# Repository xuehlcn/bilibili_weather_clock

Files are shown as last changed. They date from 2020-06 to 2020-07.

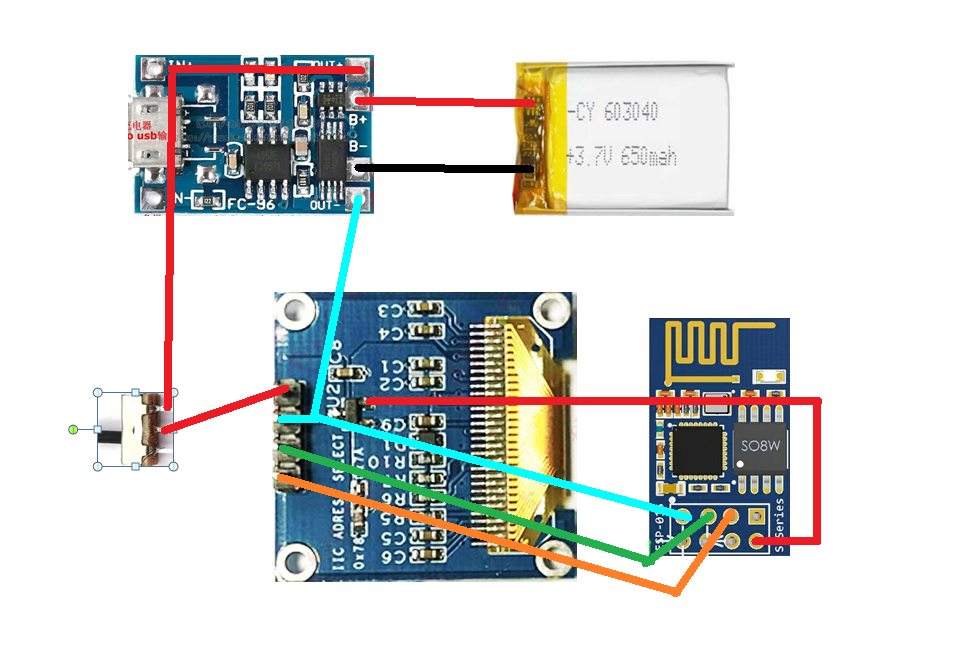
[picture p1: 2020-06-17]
接线/电路接线.png

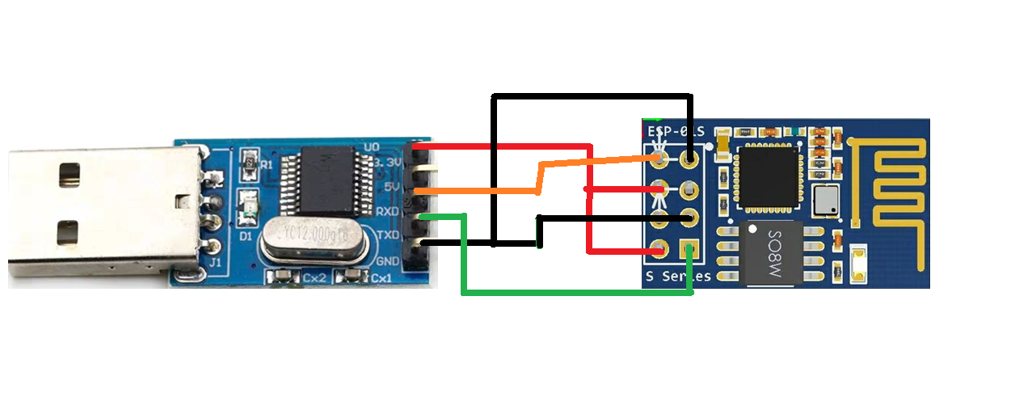
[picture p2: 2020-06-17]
接线/上传程序接线.png

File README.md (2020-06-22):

# 哔哩哔哩网络天气时钟小电视（太极创客小凯制作）

### 观看该项目可点击视频地址：https://www.bilibili.com/video/BV1FV411k7Pq/

输入图片说明

输入图片说明

## 材料
| 材料 | 规格 | 参考价格 |
| --- | ---| --- |
| ESP01s | 或者其他型号，尺寸合适即可 | 6-7元 |
| OLED | 0.96寸，带3.3V稳压，尺寸见下方图片 | 9-11元 |
| 3.7V充电模块 | 见下方图片 | 1-2元 |
| 3.7V锂电池 | 型号602525或者502525，尺寸见下方图片  | 5-7元 |
| 三脚开关 | 宽3.7长8.5 | 0.1元 |
| 外壳 | 见3D文件 | |
| 线 | 若干 | |
| 亚克力 | 见图纸CAD | 5元 |
| 螺钉 | M2*10 | 1元 |
| USB转TTL | 有3.3V的 | 3-5元 |

输入图片说明

## 焊接/连线  
上传程序接线

| ESP01S | USB-TTF |
| --- | --- |
| GND | GND |
| 3.3V | 3.3V |
| RX | TX |
| TX | RX |
| EN | 3.3V |
| IO0 | GND |

输入图片说明

主电路接线

（注意ESP01模块的VCC是接在OLED屏幕的3.3V降压管的引脚上哦，还有就是你的模块引脚跟图片可能不一样，注意区分，灵活变通）

| ESP01S | OLED |
| --- | --- |
| 3.3V | 3.3V降压管 |
| GND | GND |
| IO0 | SDA |
| IO2 | SCL |

输入图片说明

## 3D打印外壳 
见3D文件夹，可自行修改

目前只针对0.96寸

1.3寸后期更新

## 程序  
需要修改的地方修改的地方我已在程序注释，请小伙伴认真阅读 

## 其他
网络时钟目前获取的是中科院以及阿里云的NTP

天气用的是和风天气API，可百度搜索并自行注册

## 太极创客团队信息

太极创客官网地址：http://www.taichi-maker.com/

太极创客哔哩哔哩主页：https://space.bilibili.com/103589285

太极创客YouTube：https://www.youtube.com/channel/UC8EkxMr5gGnrb9adVgR-UJw

太极创客GitHub：https://github.com/taichi-maker

太极创客码云：https://gitee.com/taijichuangke

## ESP8266-Seniverse库项目开发人员

小凯：https://gitee.com/xiaoxiaokai

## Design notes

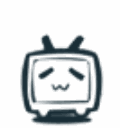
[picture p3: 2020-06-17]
取模软件/小电视动画1/xiaodianshi(2).gif

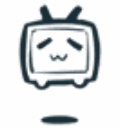
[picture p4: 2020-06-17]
取模软件/小电视动画1/xiaodianshi(2)_4.jpeg

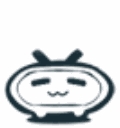
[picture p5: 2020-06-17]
取模软件/小电视动画1/xiaodianshi(2)_6.jpeg

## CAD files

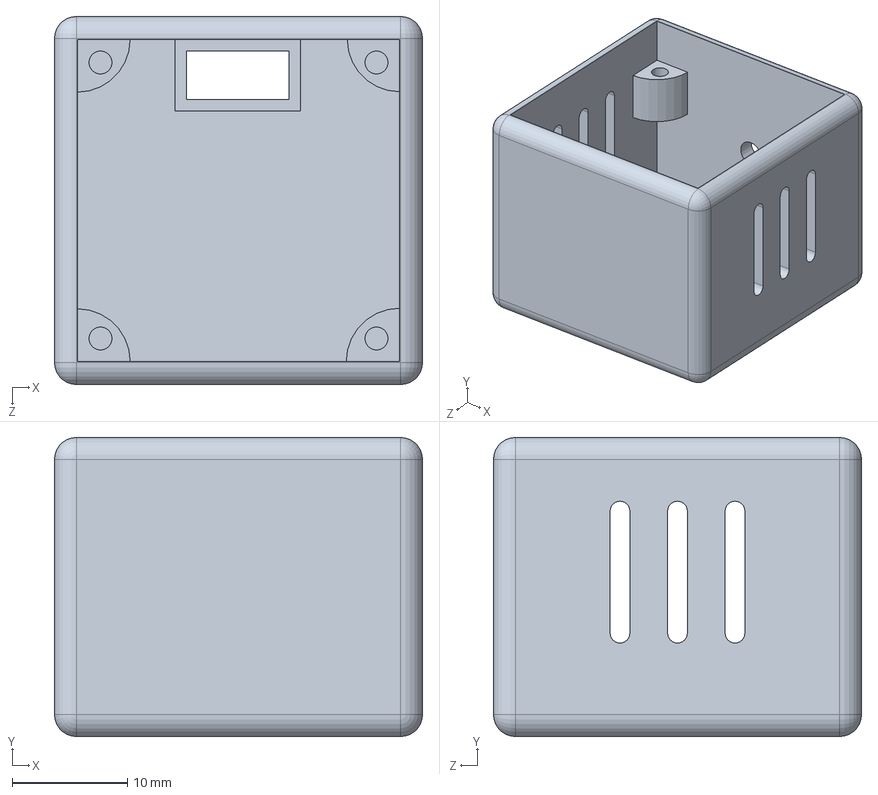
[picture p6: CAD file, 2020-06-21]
小电视3D文件/小电视 - 带散热孔.SLDPRT
32.0 x 26.0 x 32.0 mm

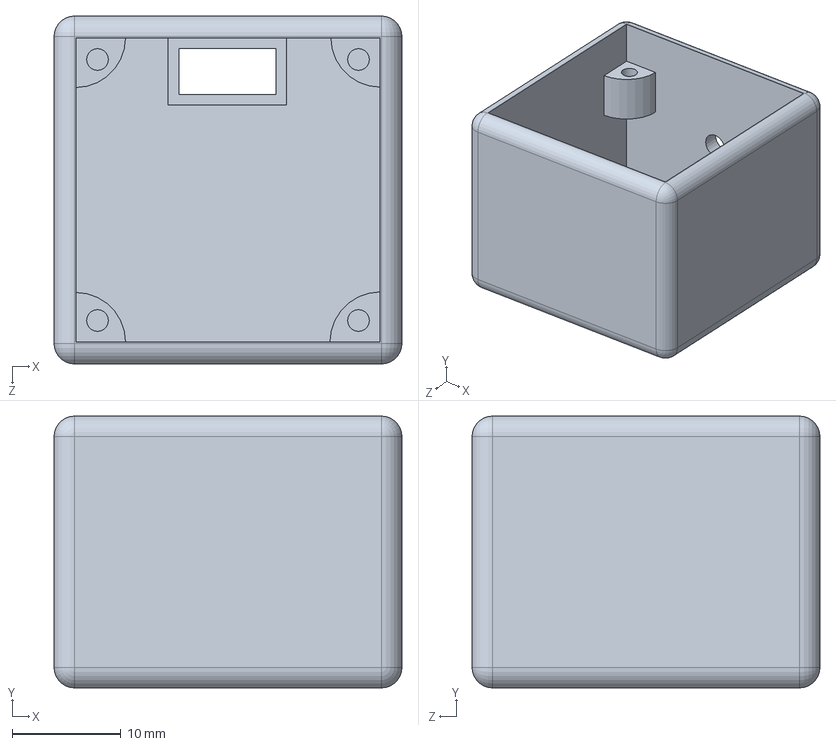
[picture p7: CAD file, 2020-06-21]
小电视3D文件/小电视.SLDPRT
32.0 x 25.0 x 32.0 mm

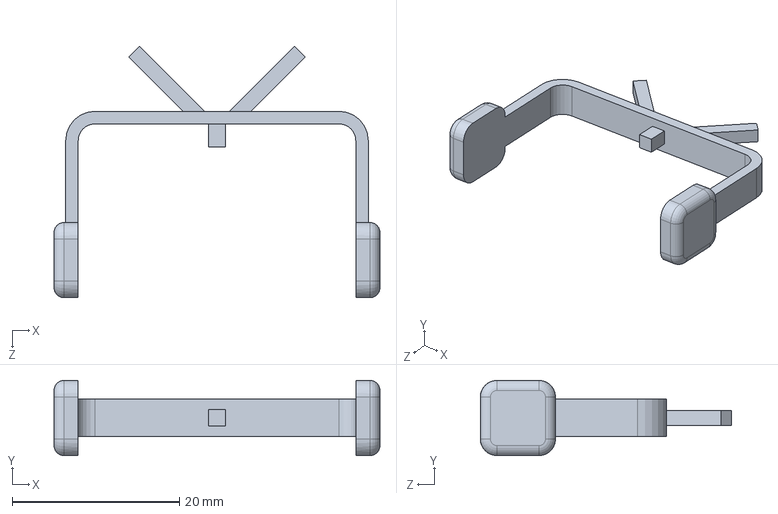
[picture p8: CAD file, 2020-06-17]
小电视3D文件/耳机天线.SLDPRT
39.0 x 9.00 x 30.1 mm

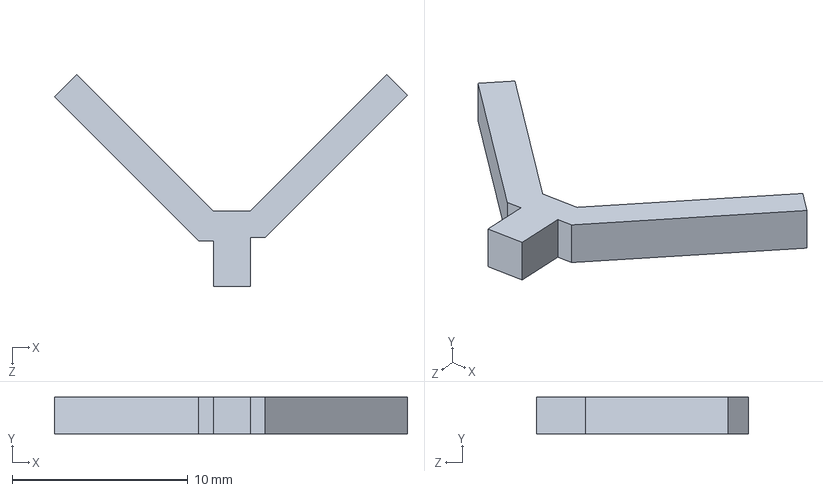
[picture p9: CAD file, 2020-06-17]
小电视3D文件/天线.SLDPRT
20.1 x 2.10 x 12.1 mm

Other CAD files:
小电视3D文件/CAD亚克力/2毫米厚.dwg
小电视3D文件/天线.STL
小电视3D文件/小电视 - 带散热孔.STL
小电视3D文件/小电视.STL
小电视3D文件/耳机天线.STL

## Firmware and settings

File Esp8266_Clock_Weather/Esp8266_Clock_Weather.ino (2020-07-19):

#include <Arduino.h>
#include <ESP8266WiFi.h>
#include <ESP8266HTTPClient.h>

#include <DNSServer.h>//密码直连将其三个库注释
#include <ESP8266WebServer.h>
#include <CustomWiFiManager.h>

#include <time.h>                       
#include <sys/time.h>                  
#include <coredecls.h>      


//#include "SH1106Wire.h"   //1.3寸用这个
#include "SSD1306Wire.h"    //0.96寸用这个
#include "OLEDDisplayUi.h"
#include "HeFeng.h"
#include "WeatherStationFonts.h"
#include "WeatherStationImages.h"

/***************************
   Begin Settings
 **************************/

const char* WIFI_SSID = "xiaokai";  //填写你的WIFI名称及密码
const char* WIFI_PWD = "12345678k";

const char* BILIBILIID = "167480182";  //填写你的B站账号

//由于太多人使用我的秘钥，导致获取次数超额，所以不提供秘钥了，大家可以到https://dev.heweather.com/获取免费的
const char* HEFENG_KEY = "xxxxxxxxxxxxxxxxxxxxxx";//填写你的和风天气秘钥
const char* HEFENG_LOCATION = "CN101290703";//填写你的城市ID,可到https://where.heweather.com/index.html查询
//const char* HEFENG_LOCATION = "auto_ip";//自动IP定位

#define TZ              8      // 中国时区为8
#define DST_MN          0      // 默认为0

const int UPDATE_INTERVAL_SECS = 5 * 60; // 5分钟更新一次天气
const int UPDATE_CURR_INTERVAL_SECS = 2 * 59; // 2分钟更新一次粉丝数

const int I2C_DISPLAY_ADDRESS = 0x3c;  //I2c地址默认
#if defined(ESP8266)
const int SDA_PIN = 0;  //引脚连接
const int SDC_PIN = 2;  //
#endif

const String WDAY_NAMES[] = {"Sun", "Mon", "Tue", "Wed", "Thu", "Fri", "Sat"};  //星期
const String MONTH_NAMES[] = {"Jan", "Feb", "Mar", "Apr", "May", "Jun", "Jul", "Aug", "Sep", "Oct", "Nov", "Dec"};  //月份

// web配网页面自定义我的图标请随便使用一个图片转base64工具转换https://tool.css-js.com/base64.html, 64*64
const char Icon[] PROGMEM = "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";

/***************************
   End Settings
 **************************/
 
//SH1106Wire     display(I2C_DISPLAY_ADDRESS, SDA_PIN, SDC_PIN);   // 1.3寸用这个
SSD1306Wire     display(I2C_DISPLAY_ADDRESS, SDA_PIN, SDC_PIN);   // 0.96寸用这个
OLEDDisplayUi   ui( &display );

HeFengCurrentData currentWeather; //实例化对象
HeFengForeData foreWeather[3];
HeFeng HeFengClient;

#define TZ_MN           ((TZ)*60)   //时间换算
#define TZ_SEC          ((TZ)*3600)
#define DST_SEC         ((DST_MN)*60)

time_t now; //实例化时间

bool readyForWeatherUpdate = false; // 天气更新标志
bool first = true;  //首次更新标志
long timeSinceLastWUpdate = 0;    //上次更新后的时间
long timeSinceLastCurrUpdate = 0;   //上次天气更新后的时间

String fans = "-1"; //粉丝数

void drawProgress(OLEDDisplay *display, int percentage, String label);   //提前声明函数
void updateData(OLEDDisplay *display);
void updateDatas(OLEDDisplay *display);
void drawDateTime(OLEDDisplay *display, OLEDDisplayUiState* state, int16_t x, int16_t y);
void drawCurrentWeather(OLEDDisplay *display, OLEDDisplayUiState* state, int16_t x, int16_t y);
void drawForecast(OLEDDisplay *display, OLEDDisplayUiState* state, int16_t x, int16_t y);
void drawForecastDetails(OLEDDisplay *display, int x, int y, int dayIndex);
void drawHeaderOverlay(OLEDDisplay *display, OLEDDisplayUiState* state);
void setReadyForWeatherUpdate();

//添加框架
//此数组保留指向所有帧的函数指针
//框架是从右向左滑动的单个视图
FrameCallback frames[] = { drawDateTime, drawCurrentWeather, drawForecast };
//页面数量
int numberOfFrames = 3;

OverlayCallback overlays[] = { drawHeaderOverlay }; //覆盖回调函数
int numberOfOverlays = 1;  //覆盖数

void setup() {
  Serial.begin(115200);
  Serial.println();
  Serial.println();

  // 屏幕初始化
  display.init();
  display.clear();
  display.display();

  display.flipScreenVertically(); //屏幕翻转
  display.setContrast(255); //屏幕亮度

  //Web配网，密码直连请注释
  webconnect();
  
  // 用固定密码连接，Web配网请注释
  //wificonnect();

  ui.setTargetFPS(30);  //刷新频率

  ui.setActiveSymbol(activeSymbole); //设置活动符号
  ui.setInactiveSymbol(inactiveSymbole); //设置非活动符号

  // 符号位置
  // 你可以把这个改成TOP, LEFT, BOTTOM, RIGHT
  ui.setIndicatorPosition(BOTTOM);

  // 定义第一帧在栏中的位置
  ui.setIndicatorDirection(LEFT_RIGHT);

  // 屏幕切换方向
  // 您可以更改使用的屏幕切换方向 SLIDE_LEFT, SLIDE_RIGHT, SLIDE_TOP, SLIDE_DOWN
  ui.setFrameAnimation(SLIDE_LEFT);

  ui.setFrames(frames, numberOfFrames); // 设置框架
  ui.setTimePerFrame(5000); //设置切换时间
  
  ui.setOverlays(overlays, numberOfOverlays); //设置覆盖

  // UI负责初始化显示
  ui.init();
  display.flipScreenVertically(); //屏幕反转

  configTime(TZ_SEC, DST_SEC, "ntp.ntsc.ac.cn", "ntp1.aliyun.com"); //ntp获取时间，你也可用其他"pool.ntp.org","0.cn.pool.ntp.org","1.cn.pool.ntp.org","ntp1.aliyun.com"
  delay(200);

}

void loop() {
  if (first) {  //首次加载
    updateDatas(&display);
    first = false;
  }
  if (millis() - timeSinceLastWUpdate > (1000L * UPDATE_INTERVAL_SECS)) { //屏幕刷新
    setReadyForWeatherUpdate();
    timeSinceLastWUpdate = millis();
  }
  if (millis() - timeSinceLastCurrUpdate > (1000L * UPDATE_CURR_INTERVAL_SECS)) { //粉丝数更新
    HeFengClient.fans(&currentWeather, BILIBILIID);
    fans = String(currentWeather.follower);
    timeSinceLastCurrUpdate = millis();
  }

  if (readyForWeatherUpdate && ui.getUiState()->frameState == FIXED) { //天气更新
    updateData(&display);
  }

  int remainingTimeBudget = ui.update(); //剩余时间预算

  if (remainingTimeBudget > 0) {
    //你可以在这里工作如果你低于你的时间预算。
    delay(remainingTimeBudget);
  }
  
}

//void wificonnect() {  //WIFI密码连接，Web配网请注释
//  WiFi.begin(WIFI_SSID, WIFI_PWD);
//  while (WiFi.status() != WL_CONNECTED) {
//    Serial.print('.');
//    delay(80);
//    display.clear();
//    display.drawXbm(34, 0, bili_Logo_width, bili_Logo_height, bili_Logo_5);
//    display.display();
//    delay(80);
//    display.clear();
//    display.drawXbm(34, 0, bili_Logo_width, bili_Logo_height, bili_Logo_6);
//    display.display();
//    delay(80);
//    display.clear();
//    display.drawXbm(34, 0, bili_Logo_width, bili_Logo_height, bili_Logo_7);
//    display.display();
//    delay(80);
//    display.clear();
//    display.drawXbm(34, 0, bili_Logo_width, bili_Logo_height, bili_Logo_8);
//    display.display();
//    delay(80);
//    display.clear();
//    display.drawXbm(34, 0, bili_Logo_width, bili_Logo_height, bili_Logo_1);
//    display.display();
//    delay(80);
//    display.clear();
//    display.drawXbm(34, 0, bili_Logo_width, bili_Logo_height, bili_Logo_2);
//    display.display();
//    delay(80);
//    display.clear();
//    display.drawXbm(34, 0, bili_Logo_width, bili_Logo_height, bili_Logo_3);
//    display.display();
//    delay(80);
//    display.clear();
//    display.drawXbm(34, 0, bili_Logo_width, bili_Logo_height, bili_Logo_4);
//    display.display();
//  }
//  Serial.println("");
//  delay(500);
//}

void webconnect() {  ////Web配网，密码直连将其注释
  display.clear();
  display.drawXbm(0, 0, 128, 64, bilibili); //显示哔哩哔哩
  display.display();

  WiFiManager wifiManager;  //实例化WiFiManager
  wifiManager.setDebugOutput(false); //关闭Debug
  //wifiManager.setConnectTimeout(10); //设置超时
  wifiManager.setHeadImgBase64(FPSTR(Icon)); //设置图标
  wifiManager.setPageTitle("欢迎来到小凯的WiFi配置页");  //设置页标题

  if (!wifiManager.autoConnect("XiaoKai-IOT-Display")) {  //AP模式
    Serial.println("连接失败并超时");
    //重新设置并再试一次，或者让它进入深度睡眠状态
    ESP.restart();
    delay(1000);
  }
  Serial.println("connected...^_^");
  yield();
}

void drawProgress(OLEDDisplay *display, int percentage, String label) {    //绘制进度
  display->clear();
  display->setTextAlignment(TEXT_ALIGN_CENTER);
  display->setFont(ArialMT_Plain_10);
  display->drawString(64, 10, label);
  display->drawProgressBar(2, 28, 124, 10, percentage);
  display->display();
}

void updateData(OLEDDisplay *display) {  //天气更新
  HeFengClient.doUpdateCurr(&currentWeather, HEFENG_KEY, HEFENG_LOCATION);
  HeFengClient.doUpdateFore(foreWeather, HEFENG_KEY, HEFENG_LOCATION);
  readyForWeatherUpdate = false;
}

void updateDatas(OLEDDisplay *display) {  //首次天气更新
  drawProgress(display, 0, "Updating fansnumb...");
  HeFengClient.fans(&currentWeather, BILIBILIID);
  fans = String(currentWeather.follower);
  
  drawProgress(display, 33, "Updating weather...");
  HeFengClient.doUpdateCurr(&currentWeather, HEFENG_KEY, HEFENG_LOCATION);
  
  drawProgress(display, 66, "Updating forecasts...");
  HeFengClient.doUpdateFore(foreWeather, HEFENG_KEY, HEFENG_LOCATION);
  
  readyForWeatherUpdate = false;
  drawProgress(display, 100, "Done...");
  delay(200);
  
}

void drawDateTime(OLEDDisplay *display, OLEDDisplayUiState* state, int16_t x, int16_t y) {  //显示时间
  now = time(nullptr);
  struct tm* timeInfo;
  timeInfo = localtime(&now);
  char buff[16];

  display->setTextAlignment(TEXT_ALIGN_CENTER);
  display->setFont(ArialMT_Plain_16);
  String date = WDAY_NAMES[timeInfo->tm_wday];

  sprintf_P(buff, PSTR("%04d-%02d-%02d  %s"), timeInfo->tm_year + 1900, timeInfo->tm_mon + 1, timeInfo->tm_mday, WDAY_NAMES[timeInfo->tm_wday].c_str());
  display->drawString(64 + x, 5 + y, String(buff));
  display->setFont(ArialMT_Plain_24);

  sprintf_P(buff, PSTR("%02d:%02d:%02d"), timeInfo->tm_hour, timeInfo->tm_min, timeInfo->tm_sec);
  display->drawString(64 + x, 22 + y, String(buff));
  display->setTextAlignment(TEXT_ALIGN_LEFT);
}

void drawCurrentWeather(OLEDDisplay *display, OLEDDisplayUiState* state, int16_t x, int16_t y) {  //显示天气
  display->setFont(ArialMT_Plain_10);
  display->setTextAlignment(TEXT_ALIGN_CENTER);
  display->drawString(64 + x, 38 + y, currentWeather.cond_txt + "    |   Wind: " + currentWeather.wind_sc + "  ");

  display->setFont(ArialMT_Plain_24);
  display->setTextAlignment(TEXT_ALIGN_LEFT);
  String temp = currentWeather.tmp + "°C" ;
  display->drawString(60 + x, 3 + y, temp);
  display->setFont(ArialMT_Plain_10);
  display->drawString(62 + x, 26 + y, currentWeather.fl + "°C | " + currentWeather.hum + "%");
  display->setFont(Meteocons_Plain_36);
  display->setTextAlignment(TEXT_ALIGN_CENTER);
  display->drawString(32 + x, 0 + y, currentWeather.iconMeteoCon);
}

void drawForecast(OLEDDisplay *display, OLEDDisplayUiState* state, int16_t x, int16_t y) {  //天气预报
  drawForecastDetails(display, x, y, 0);
  drawForecastDetails(display, x + 44, y, 1);
  drawForecastDetails(display, x + 88, y, 2);
}

void drawForecastDetails(OLEDDisplay *display, int x, int y, int dayIndex) {  //天气预报

  display->setTextAlignment(TEXT_ALIGN_CENTER);
  display->setFont(ArialMT_Plain_10);
  display->drawString(x + 20, y, foreWeather[dayIndex].datestr);
  display->setFont(Meteocons_Plain_21);
  display->drawString(x + 20, y + 12, foreWeather[dayIndex].iconMeteoCon);

  String temp = foreWeather[dayIndex].tmp_min + " | " + foreWeather[dayIndex].tmp_max;
  display->setFont(ArialMT_Plain_10);
  display->drawString(x + 20, y + 34, temp);
  display->setTextAlignment(TEXT_ALIGN_LEFT);
}
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

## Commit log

2020-06-17 添加项目
    [2毫米厚.dwg, 天线.SLDPRT, 天线.STL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]
2020-06-17 重修调整了文件资源结构
2020-06-17 修改remdme
2020-06-21 修改3D
    [小电视 - 带散热孔.SLDPRT, 小电视 - 带散热孔.STL, 小电视.SLDPRT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]
2020-07-19 删除秘钥
